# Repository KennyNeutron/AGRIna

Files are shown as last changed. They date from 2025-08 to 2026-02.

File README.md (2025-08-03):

# AGRIna: Smart Soil Analyzer for Rice Crops

## Overview

AGRIna is a portable Arduino & LoRa-based smart soil analyzer designed to help the Department of Agriculture obtain real-time soil condition data directly from the field. By measuring key soil parameters—nitrogen (N), phosphorus (P), and potassium (K) in parts per million (ppm), pH (0–14 scale), and temperature (°C)—AGRIna accelerates decision-making for rice crop management. Data are wirelessly transmitted via LoRa to an ESP32, which forwards readings to a web application featuring live dashboards, historical logs, and simple soil health recommendations.

## Block Diagram

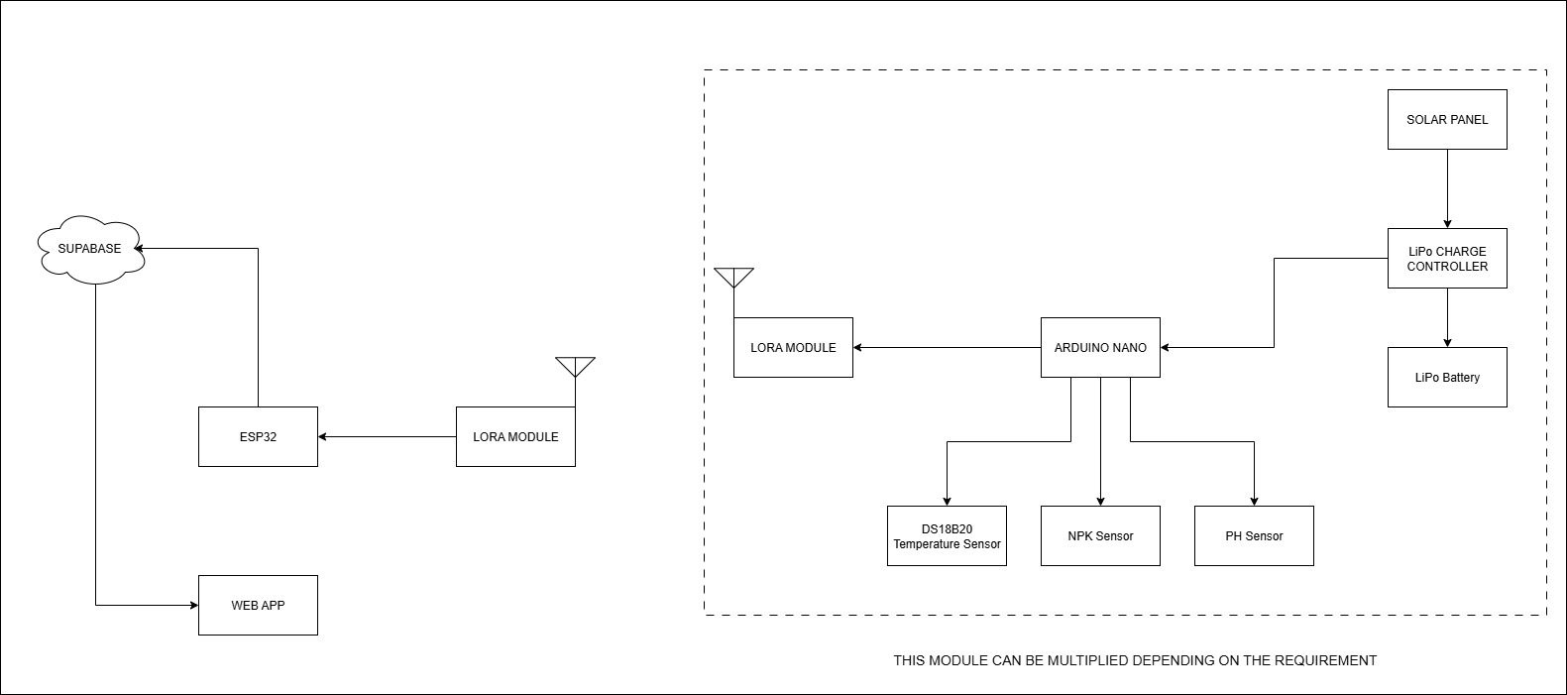
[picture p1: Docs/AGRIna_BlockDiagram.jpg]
Block Diagram


## Features

- **Real-time Sensing**: NPK (ppm), pH (0–14), and temperature (°C)
- **Multi-Module Support**: Up to three simultaneous sensor modules for comparative field analysis
- **Wireless Transmission**: LoRa communication between Arduino nanos and ESP32
- **Web Dashboard**: Live readings, interactive graphs, historical data logs
- **Automated Recommendations**: Simple fertilizer and soil amendment suggestions based on sensor results
- **Power Options**: LiPo battery with charge controller and optional solar panel support

## Hardware Requirements

- **Sensor Module (×3)**
  - Arduino Nano
  - LoRa transceiver
  - DS18B20 temperature sensor
  - NPK soil sensor
  - pH sensor
  - LiPo battery, LiPo charge controller, and solar panel (optional)
- **Central Hub**
  - ESP32 development board
  - LoRa transceiver

## Software Requirements

- Arduino IDE (or PlatformIO) for Nano firmware
- ESP32 toolchain for central hub firmware
- Node.js & npm for web application
- Supabase account (for database and hosting)

## Installation

1. **Clone the repository**

   ```bash
   git clone <repo-url>
   cd AGRIna
   ```

2. **Prepare the Sensor Module**

   - Place `AGRIna_BlockDiagram.jpg` in the project root.
   - Open `sensor_module.ino` in Arduino IDE.
   - Select **Arduino Nano** and upload the sketch.

3. **Flash the ESP32 Hub**

   - Open `hub_firmware.ino` (or PlatformIO project) in your IDE.
   - Select **ESP32** board and upload.

4. **Set Up the Web App**
   ```bash
   cd web-app
   npm install
   npm start
   ```
   - Configure your Supabase URL and anon key in `web-app/.env`.

## Usage

1. Power on each sensor module (via LiPo battery or solar).
2. Modules collect soil data and transmit via LoRa.
3. ESP32 receives, then pushes data to the Supabase backend.
4. Open the web dashboard in your browser to view live data, graphs, and recommendations.

## Contributing

Contributions are welcome! Please fork the repo, create a feature branch, and submit a pull request. For major changes, open an issue first to discuss your ideas.

## License

This project is licensed under the MIT License. See [LICENSE](LICENSE) for details.

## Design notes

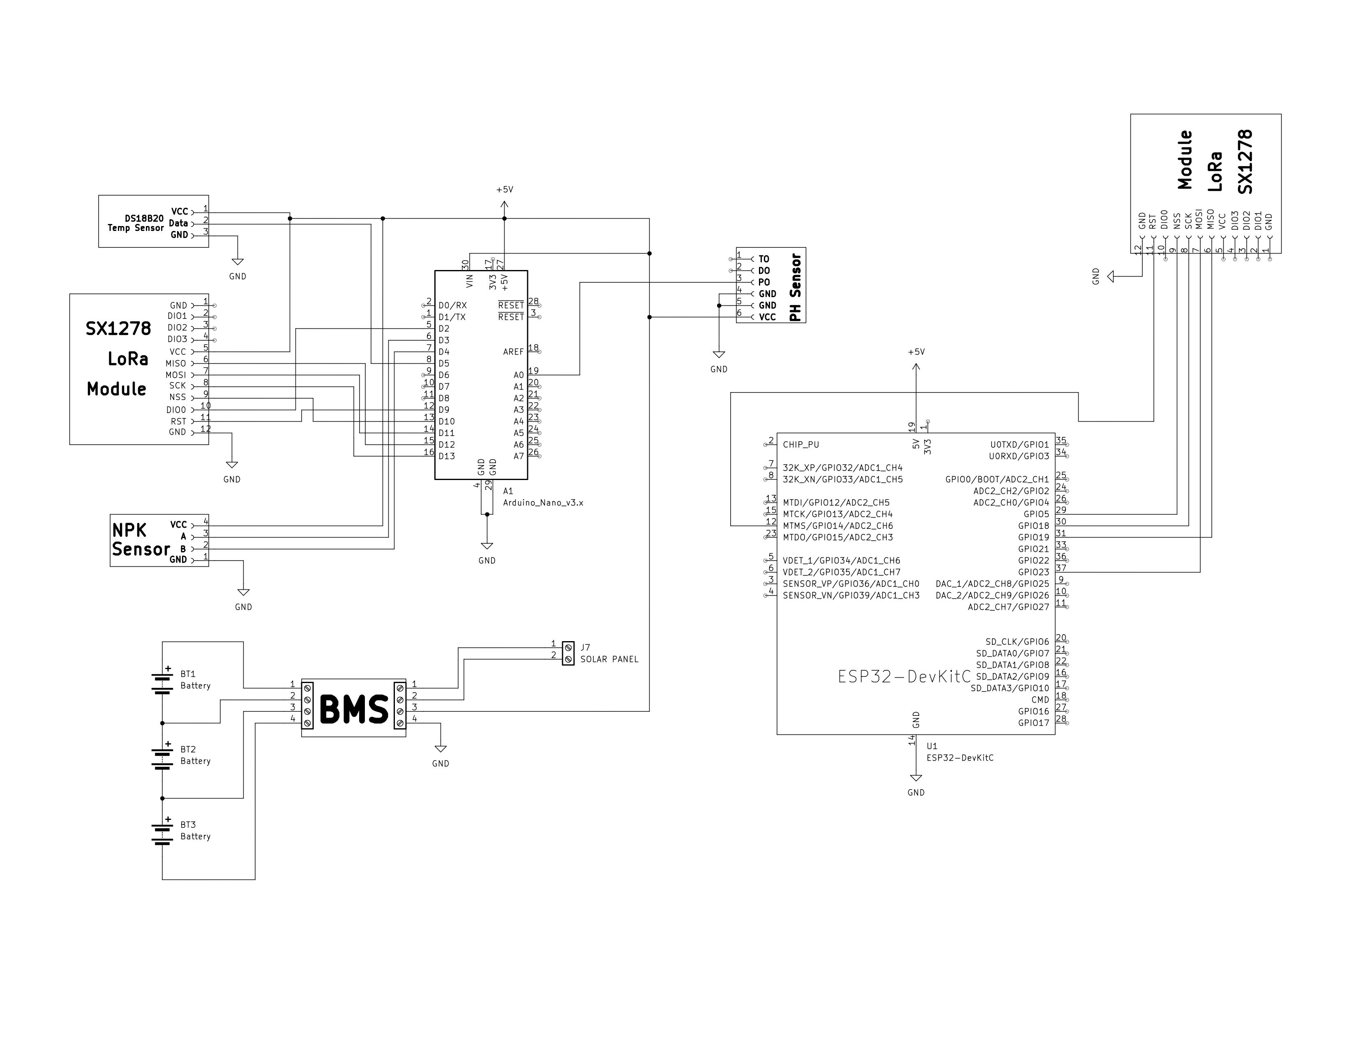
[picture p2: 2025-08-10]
Docs/AGRINa_FullSchematic.jpg

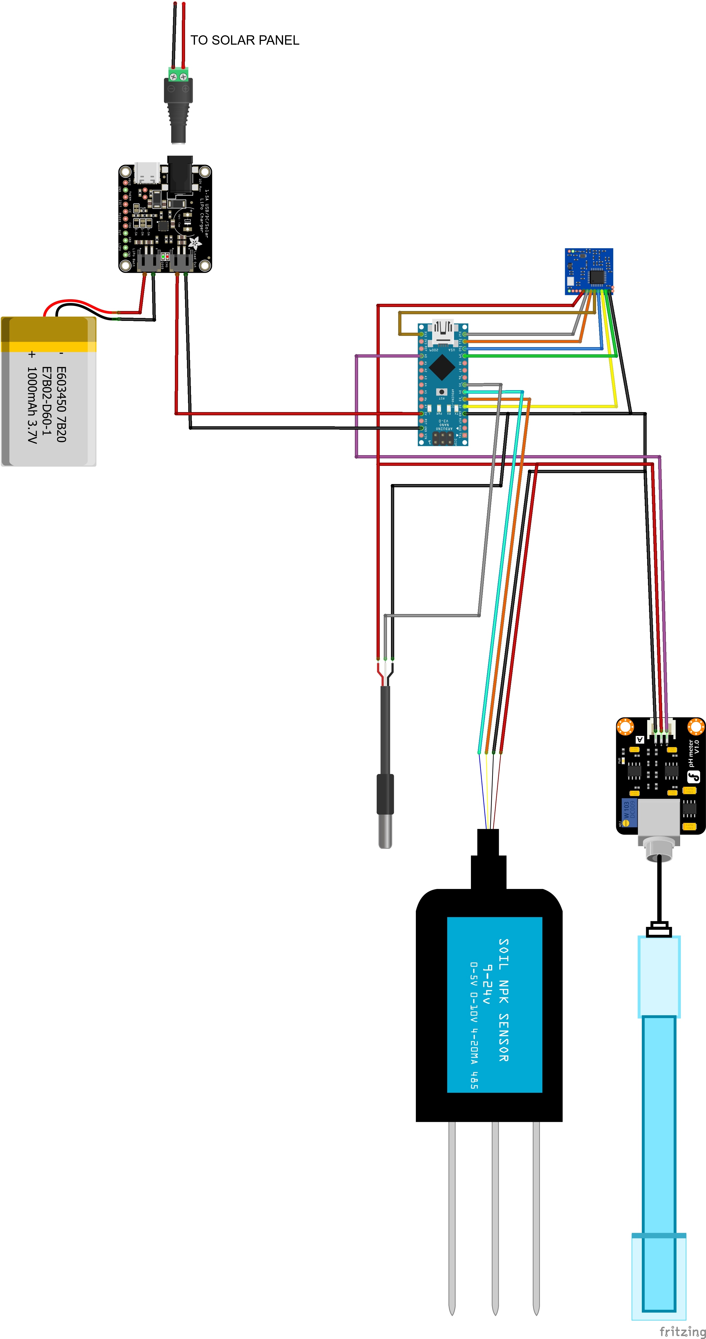
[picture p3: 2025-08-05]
Docs/Agrina Module_bb.jpg

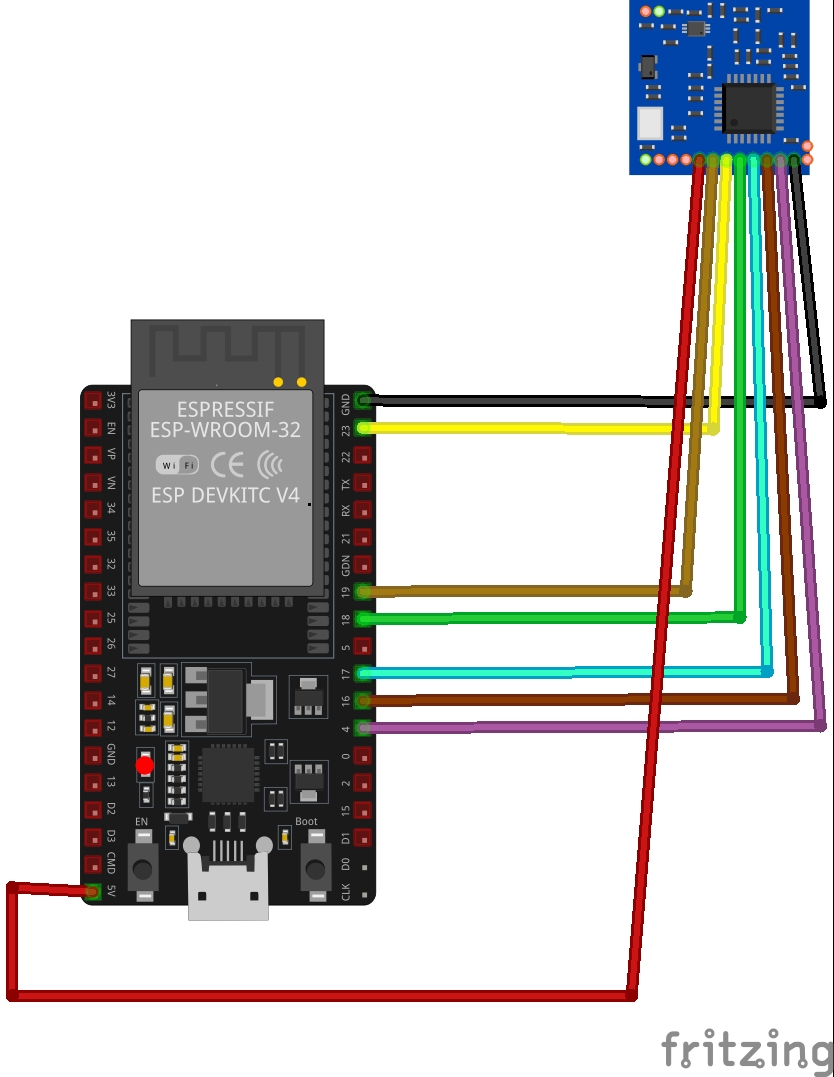
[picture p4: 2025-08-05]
Docs/Agrina Receiver Module_bb.jpg

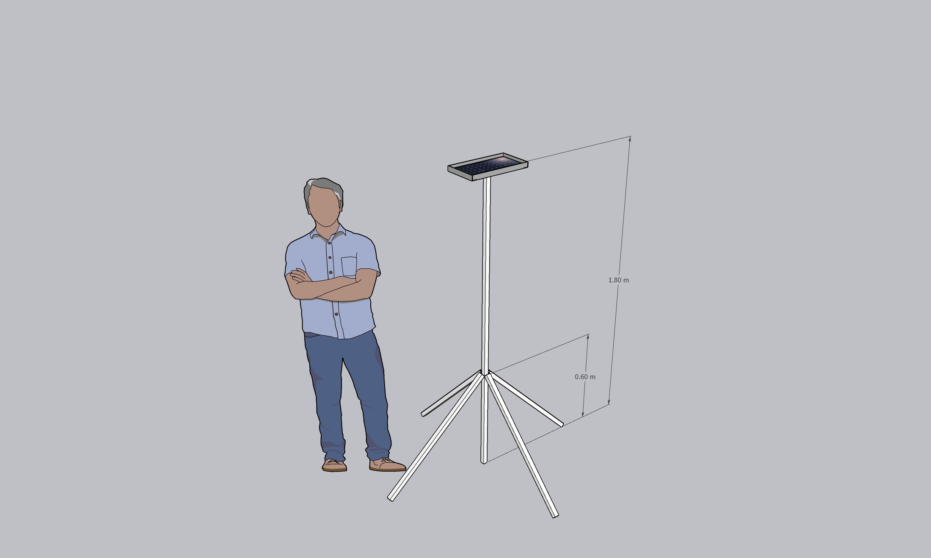
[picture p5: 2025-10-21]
3D/Agrina Struct iso.jpg

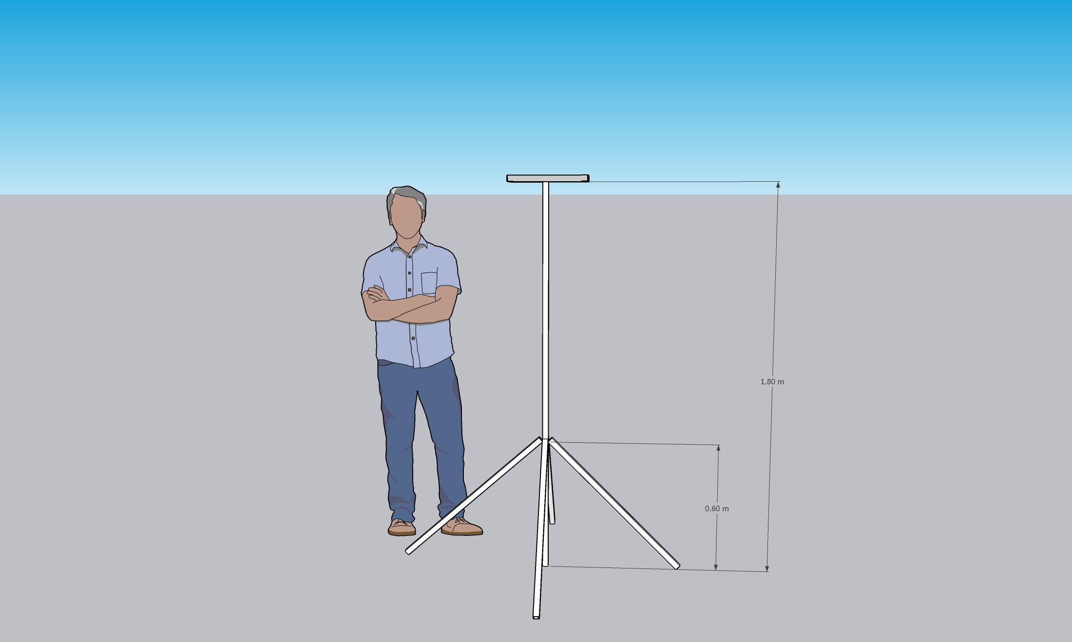
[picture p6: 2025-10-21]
3D/Agrina Struct.jpg

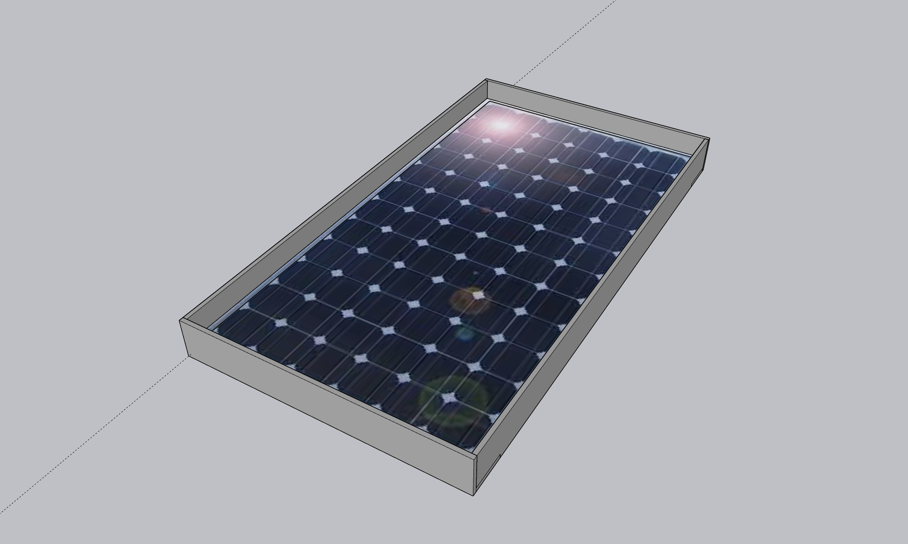
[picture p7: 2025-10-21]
3D/SolarCase_w_Solar.jpg

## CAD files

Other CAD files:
3D/Agrina Struct.skp

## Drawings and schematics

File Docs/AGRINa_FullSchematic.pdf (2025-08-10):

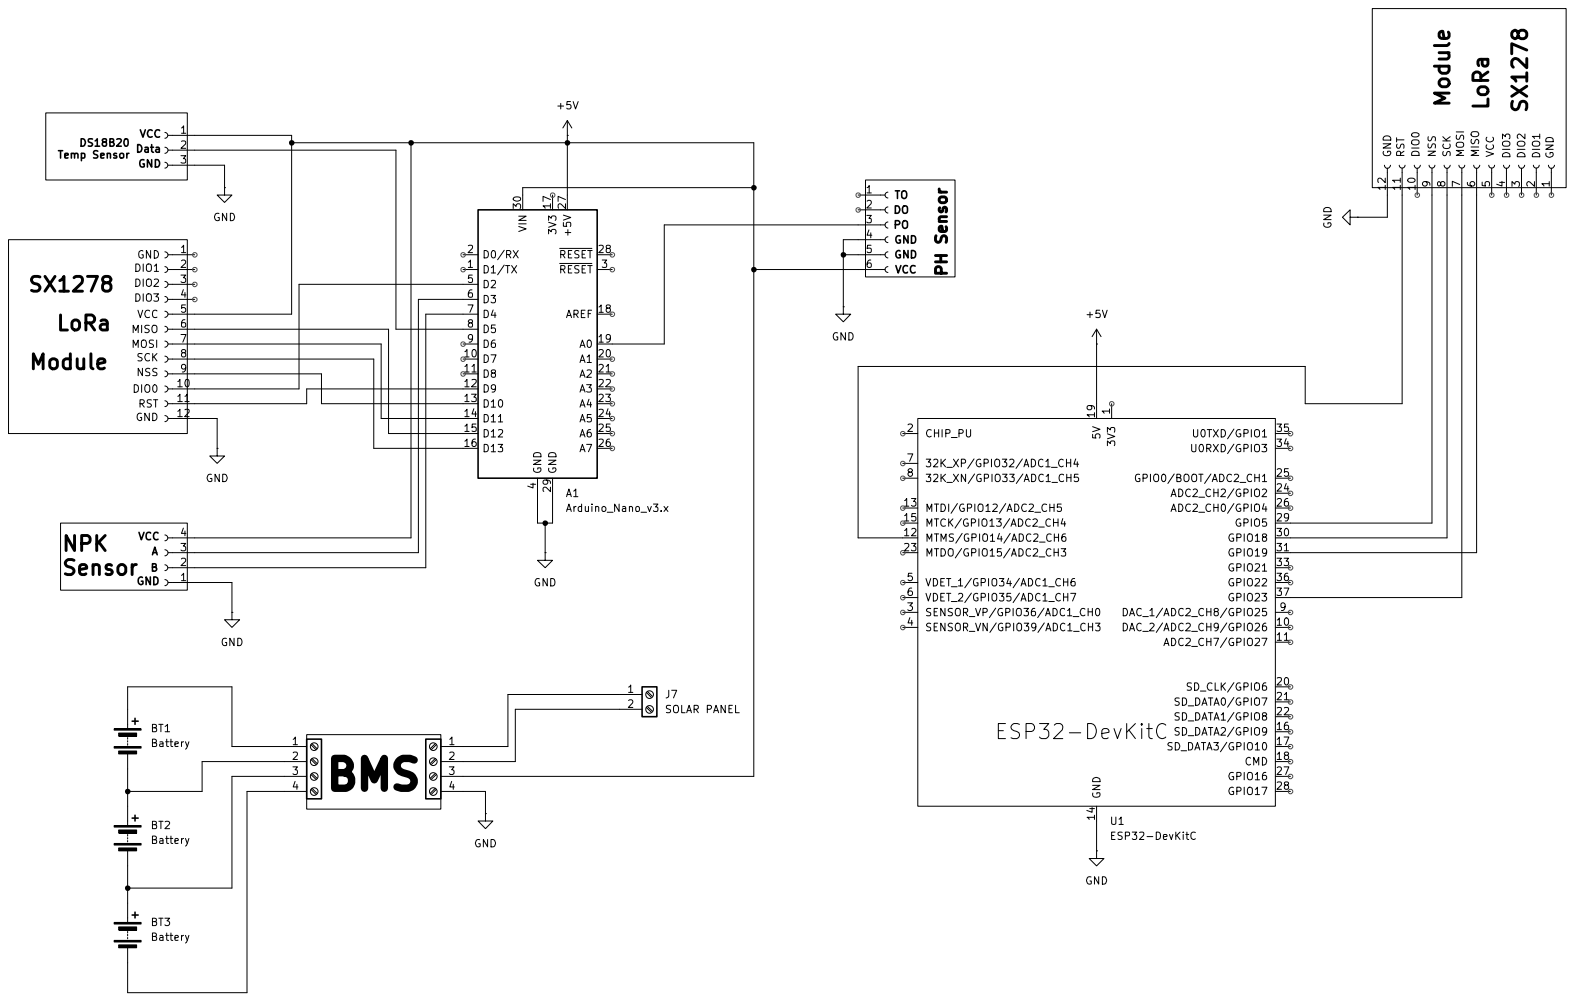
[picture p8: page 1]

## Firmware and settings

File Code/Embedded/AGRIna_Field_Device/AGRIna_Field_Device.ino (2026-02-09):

// AGRIna_Field_Device.ino  —  Transmitter (Arduino Nano + RA-02/SX1278)
// Requires: Sandeep Mistry's LoRa library (Library Manager -> "LoRa" by Sandeep Mistry)

#include <SPI.h>
#include <LoRa.h>
#include "DataStructure.h"  // contains AGRInaData Data_AGRIna (packed)

// === LoRa Radio Pins (Arduino Nano) ===
// NSS(SS)=10, RST=9, DIO0=2  (matches your wiring)
static const int PIN_LORA_SS = 10;
static const int PIN_LORA_RST = 9;
static const int PIN_LORA_DIO0 = 2;

// === LoRa Frequency ===
// Change to 868E6 or 915E6 if you use those bands.
static const long LORA_FREQUENCY = 433E6;

// Device ID
static const uint8_t MY_DEVICE_ID = 0x01;

// Send every N ms
static const uint32_t TX_INTERVAL_MS = 1000UL;
uint32_t lastTx = 0;

// Optional: a simple sequence counter you can add later if needed
uint32_t txCount = 0;

void hexDump(const uint8_t* buf, size_t len) {
  for (size_t i = 0; i < len; i++) {
    if (i && (i % 16 == 0)) Serial.println();
    if (buf[i] < 0x10) Serial.print('0');
    Serial.print(buf[i], HEX);
    Serial.print(' ');
  }
  Serial.println();
}

void setup() {
  Serial.begin(115200);

  Serial.println(F("AGRIna LoRa TX (Arduino Nano + RA-02) starting..."));

  // Set initial values for the struct (for now, static demo values)
  // Tip: Header/Footer can be used for quick packet framing checks
  Data_AGRIna.Header = 0x55;
  Data_AGRIna.AN_DeviceID = MY_DEVICE_ID;
  //   Data_AGRIna.AN_SoilTemperature = 27.5f;
  //   Data_AGRIna.AN_pH = 6.80f;
  //   Data_AGRIna.AN_Nitrogen = 20;  // mg/kg or your chosen unit
  //   Data_AGRIna.AN_Phosphorus = 10;
  //   Data_AGRIna.AN_Potassium = 15;
  Data_AGRIna.Footer = 0xAA;

  // Configure LoRa pins and radio
  LoRa.setPins(PIN_LORA_SS, PIN_LORA_RST, PIN_LORA_DIO0);

  if (!LoRa.begin(LORA_FREQUENCY)) {
    Serial.println(F("[ERR] LoRa init failed. Check wiring/frequency."));
    while (true) { delay(1000); }
  }

  // Optional radio tweaks
  LoRa.setTxPower(17);             // 2..20 (dBm), watch legal limits
  LoRa.setSpreadingFactor(7);      // 6..12
  LoRa.setSignalBandwidth(125E3);  // 7.8E3..500E3
  LoRa.setCodingRate4(5);          // 5..8

  Serial.print(F("Struct size (bytes): "));
  Serial.println(sizeof(Data_AGRIna));
  Serial.println(F("Initial payload (hex):"));
  hexDump(reinterpret_cast<uint8_t*>(&Data_AGRIna), sizeof(Data_AGRIna));

  lastTx = millis();

  SoilSensor_setup();
}

void loop() {
  SoilSensor_loop();

  // Check for incoming packets (Repeater Logic)
  int packetSize = LoRa.parsePacket();
  if (packetSize == sizeof(AGRInaData)) {
    AGRInaData receivedData;
    LoRa.readBytes((uint8_t*)&receivedData, sizeof(receivedData));

    // Validate Header, Footer and ensure it's not from us
    if (receivedData.Header == 0x55 && receivedData.Footer == 0xAA && receivedData.AN_DeviceID != MY_DEVICE_ID) {
      Serial.print(F("Repeater: RX from 0x"));
      Serial.println(receivedData.AN_DeviceID, HEX);

      delay(random(50, 200));  // Random delay to minimize collisions

      LoRa.beginPacket();
      LoRa.write((uint8_t*)&receivedData, sizeof(receivedData));
      LoRa.endPacket();

      Serial.println(F("Repeater: Fwd done."));
    }
  }

  const uint32_t now = millis();
  if (now - lastTx >= TX_INTERVAL_MS) {
    lastTx = now;

    // (Optional) Mutate values here if you want to see changes over time
    // Example: Data_AGRIna.AN_SoilTemperature += 0.1f;

    // Transmit the raw struct
    LoRa.beginPacket();
    LoRa.write((uint8_t*)&Data_AGRIna, sizeof(Data_AGRIna));
    LoRa.endPacket();

    txCount++;
    Serial.print(F("TX #"));
    Serial.print(txCount);
    Serial.print(F("  bytes="));
    Serial.print(sizeof(Data_AGRIna));
    Serial.print(F("  ID="));
    Serial.print(Data_AGRIna.AN_DeviceID);
    Serial.print(F("  T="));
    Serial.print(Data_AGRIna.AN_SoilTemperature, 2);
    Serial.print(F("  pH="));
    Serial.print(Data_AGRIna.AN_pH, 2);
    Serial.print(F("  NPK="));
    Serial.print(Data_AGRIna.AN_Nitrogen);
    Serial.print('/');
    Serial.print(Data_AGRIna.AN_Phosphorus);
    Serial.print('/');
    Serial.print(Data_AGRIna.AN_Potassium);
    Serial.println();
  }
}

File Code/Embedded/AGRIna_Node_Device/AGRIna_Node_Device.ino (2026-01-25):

#include "variables.h"
#include <WiFi.h>
#include <HTTPClient.h>
#include <SPI.h>
#include <LoRa.h>
#include "DataStructure.h"  // defines packed AGRInaData + global Data_AGRIna (unused here) :contentReference[oaicite:1]{index=1}

// ==== ESP32 LoRa Pins (match your wiring) ====
static const int PIN_LORA_SS = 5;     // NSS / CS
static const int PIN_LORA_RST = 14;   // RESET
static const int PIN_LORA_DIO0 = 26;  // DIO0

// ==== LoRa Radio Settings ====
static const long LORA_FREQUENCY = 433E6;  // change to 868E6 or 915E6 as applicable

// Optional: Expected header/footer for quick validation
static const uint8_t kHeader = 0x55;
static const uint8_t kFooter = 0xAA;

uint32_t last_update = 0;
uint32_t Supabase_Update_Interval = 10000;

uint8_t rxDeviceID = 0;

void hexDump(const uint8_t* buf, size_t len) {
  for (size_t i = 0; i < len; i++) {
    if (i && (i % 16 == 0)) Serial.println();
    if (buf[i] < 0x10) Serial.print('0');
    Serial.print(buf[i], HEX);
    Serial.print(' ');
  }
  Serial.println();
}

void setup() {
  Serial.begin(115200);
  Serial.println("AGRIna Node Device Starting...");
  LED_Setup();

  WiFi.begin(ssid, password);
  Serial.println("Connecting to WiFi");
  while (WiFi.status() != WL_CONNECTED) {
    LEDred_On();
    delay(200);
    LEDred_Off();
    delay(200);
    Serial.print(".");
  }
  LEDred_Off();
  LEDgreen_On();
  Serial.println("Connected to WiFi");

  Serial.println(F("\nAGRIna LoRa RX (ESP32 + RA-02) starting..."));
  Serial.print(F("Expecting payload bytes: "));
  Serial.println(sizeof(AGRInaData));

  LoRa.setPins(PIN_LORA_SS, PIN_LORA_RST, PIN_LORA_DIO0);
  if (!LoRa.begin(LORA_FREQUENCY)) {
    Serial.println(F("[ERR] LoRa init failed. Check wiring/frequency."));
    for (;;) { delay(1000); }
  }

  // Optional radio tuning (match TX if you changed these there)
  LoRa.setSpreadingFactor(7);
  LoRa.setSignalBandwidth(125E3);
  LoRa.setCodingRate4(5);

  Serial.println(F("[OK] LoRa ready. Waiting for packets..."));
  last_update = millis();
}

void loop() {

  int packetSize = LoRa.parsePacket();
  if (packetSize <= 0) return;

  Serial.println(F("\n--- Packet Received ---"));
  Serial.print(F("packetSize="));
  Serial.print(packetSize);
  Serial.print(F("  RSSI="));
  Serial.print(LoRa.packetRssi());
  Serial.print(F("  SNR="));
  Serial.println(LoRa.packetSnr(), 1);

  // Read all available bytes
  uint8_t buf[64];  // plenty for this struct
  int idx = 0;
  while (LoRa.available() && idx < (int)sizeof(buf)) {
    buf[idx++] = LoRa.read();
  }

  if (idx != (int)sizeof(AGRInaData)) {
    Serial.print(F("[WARN] Unexpected size. Got "));
    Serial.print(idx);
    Serial.print(F(", expected "));
    Serial.println(sizeof(AGRInaData));
    Serial.println(F("Hex dump:"));
    hexDump(buf, idx);
    return;
  }

  // Reconstruct struct
  AGRInaData rx{};
  memcpy(&rx, buf, sizeof(rx));

  // Validate header/footer
  bool ok = (rx.Header == kHeader) && (rx.Footer == kFooter);

  if (!ok) {
    Serial.println(F("[WARN] Header/Footer invalid. Dumping bytes:"));
    Serial.print(F("Header=0x"));
    Serial.print(rx.Header, HEX);
    Serial.print(F("  Footer=0x"));
    Serial.println(rx.Footer, HEX);
    hexDump(buf, idx);
    return;
  }

  // Print decoded fields
  Serial.println(F("[OK] Valid AGRInaData payload"));
  Serial.print(F("DeviceID: "));
  Serial.println(rx.AN_DeviceID);
  Serial.print(F("Soil Temp (°C): "));
  Serial.println(rx.AN_SoilTemperature, 2);
  Serial.print(F("pH: "));
  Serial.println(rx.AN_pH, 2);
  Serial.print(F("Nitrogen: "));
  Serial.println(rx.AN_Nitrogen);
  Serial.print(F("Phosphorus: "));
  Serial.println(rx.AN_Phosphorus);
  Serial.print(F("Potassium: "));
  Serial.println(rx.AN_Potassium);

  rxDeviceID=rx.AN_DeviceID;

  if ((millis() - last_update) > Supabase_Update_Interval) {
    Serial.println("\n\n\nSupa Update!!!\n\n\n");
    SupabaseUpdate(rx.AN_pH, rx.AN_SoilTemperature, rx.AN_Nitrogen, rx.AN_Phosphorus, rx.AN_Potassium);
    last_update = millis();
  }
}

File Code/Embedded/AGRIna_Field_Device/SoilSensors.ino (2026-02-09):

// File: Dual_RS485_Soil_NPK_SEN0605_or_AutoScan.ino
// Board: Arduino Nano/Uno (ATmega328P)
//
// Links (each probe has its own MAX485):
//   NPK probe  (Probe A): RO=D3, RE&DE=D4, DI=D5
//   5-in-1 probe (Probe B): RO=D6, RE&DE=D7, DI=D8
//
// Both probes run at 4800-8-N-1 here and both are ID=0x01
// (that’s OK because they are on different transceivers).
//
// Behavior:
// 1) Try DFRobot SEN0605 map for NPK (FC03 @ 0x001E..0x0020).
// 2) If that fails or returns all zeros, auto-scan common maps (FC03/FC04).
// 3) Print which method was adopted.
//
// Optional: send 'd' over Serial to dump some NPK raw registers (debug).

#include <SoftwareSerial.h>

// ---------------- Pins --------------------
// Probe A: NPK
#define A_RO_PIN 3
#define A_DI_PIN 5
#define A_REDE_PIN 4
SoftwareSerial RS485_A(A_RO_PIN, A_DI_PIN);  // (RX, TX)

// Probe B: 5-in-1 (Moisture, Temp, EC, pH)
#define B_RO_PIN 6
#define B_DI_PIN 8
#define B_REDE_PIN 7
SoftwareSerial RS485_B(B_RO_PIN, B_DI_PIN);  // (RX, TX)

// ---------------- Serial/Modbus settings ---------------
const uint32_t MB_BAUD = 4800;   // your devices work at 4800
const uint16_t TIMEOUTMS = 800;  // a bit generous at 4800

// Both are 0x01 (separate ports)
const uint8_t NPK_ID = 0x01;
const uint8_t SOIL5_ID = 0x01;

// 5-in-1 register map (common defaults)
const uint16_t SOIL5_START = 0x0000;  // Moist, Temp, EC, pH
const uint16_t SOIL5_COUNT = 4;

// DFRobot SEN0605 fixed map (per docs)
const uint8_t SEN_FC = 0x03;
const uint16_t SEN_BASE = 0x001E;  // N,P,K at 0x001E..0x0020

// ---------------- Helpers -----------------
uint16_t modbusCRC(const uint8_t *buf, uint8_t len) {
  uint16_t crc = 0xFFFF;
  for (uint8_t pos = 0; pos < len; pos++) {
    crc ^= buf[pos];
    for (uint8_t i = 0; i < 8; i++) {
      if (crc & 1) {
        crc >>= 1;
        crc ^= 0xA001;
      } else {
        crc >>= 1;
      }
    }
  }
  return crc;
}

inline void disableBothDrivers() {
  digitalWrite(A_REDE_PIN, LOW);
  digitalWrite(B_REDE_PIN, LOW);
}

// Generic Modbus read (FC = 0x03 or 0x04)
bool mbReadRegsFC(SoftwareSerial &port, uint8_t txEnPin,
                  uint8_t id, uint8_t fc, uint16_t startReg, uint16_t count,
                  uint16_t *outRegs, uint16_t timeoutMs = TIMEOUTMS) {

  uint8_t req[8] = {
    id, fc,
    (uint8_t)(startReg >> 8), (uint8_t)(startReg & 0xFF),
    (uint8_t)(count >> 8), (uint8_t)(count & 0xFF),
    0, 0
  };
  uint16_t crc = modbusCRC(req, 6);
  req[6] = (uint8_t)(crc & 0xFF);
  req[7] = (uint8_t)(crc >> 8);

  port.listen();                         // switch SoftwareSerial listener
  while (port.available()) port.read();  // clear stale bytes

  disableBothDrivers();         // only one transceiver active
  digitalWrite(txEnPin, HIGH);  // TX enable for this transceiver
  port.write(req, sizeof(req));
  port.flush();
  delay(6);                    // 4800 baud turnaround
  digitalWrite(txEnPin, LOW);  // RX

  // Expect: [ID][FC][ByteCount=2*count][data...][CRCLo][CRCHi]
  uint8_t buf[48];
  uint8_t idx = 0;
  unsigned long t0 = millis();
  while (millis() - t0 < timeoutMs) {
    if (port.available()) {
      if (idx < sizeof(buf)) buf[idx++] = port.read();
      if (idx >= 3) {
        uint8_t bc = buf[2];
        if (idx >= 3 + bc + 2) break;  // full frame received
      }
    }
  }
  if (idx < 7) return false;
  if (buf[0] != id || buf[1] != fc) return false;
  if (buf[2] != count * 2) return false;

  uint16_t rxCrc = (uint16_t)buf[idx - 1] << 8 | buf[idx - 2];
  uint16_t calc = modbusCRC(buf, idx - 2);
  if (rxCrc != calc) return false;

  for (uint16_t i = 0; i < count; i++)
    outRegs[i] = (uint16_t)buf[3 + 2 * i] << 8 | buf[4 + 2 * i];

  return true;
}

// Optional writer: FC=0x06 (set single holding register)
//  - 0x07D0: device address
//  - 0x07D1: baud (0=2400, 1=4800, 2=9600)
bool mbWriteReg06(SoftwareSerial &port, uint8_t txEnPin,
                  uint8_t id, uint16_t reg, uint16_t value,
                  uint16_t timeoutMs = TIMEOUTMS) {
  uint8_t req[8] = {
    id, 0x06,
    (uint8_t)(reg >> 8), (uint8_t)(reg & 0xFF),
    (uint8_t)(value >> 8), (uint8_t)(value & 0xFF),
    0, 0
  };
  uint16_t crc = modbusCRC(req, 6);
  req[6] = (uint8_t)(crc & 0xFF);
  req[7] = (uint8_t)(crc >> 8);

  port.listen();
  while (port.available()) port.read();

  disableBothDrivers();
  digitalWrite(txEnPin, HIGH);
  port.write(req, sizeof(req));
  port.flush();
  delay(6);
  digitalWrite(txEnPin, LOW);

  // Expect echo of the same 8 bytes
  uint8_t resp[8];
  uint8_t idx = 0;
  unsigned long t0 = millis();
  while (millis() - t0 < timeoutMs && idx < 8) {
    if (port.available()) resp[idx++] = port.read();
  }
  if (idx != 8) return false;
  return memcmp(resp, req, 8) == 0;
}

// ---------------- 5-in-1 reader ----------------
bool readSoil5(float &moist_pct, float &temp_c, float &ec_uScm, float &ph) {
  uint16_t r[SOIL5_COUNT];
  if (!mbReadRegsFC(RS485_B, B_REDE_PIN, SOIL5_ID, 0x03, SOIL5_START, SOIL5_COUNT, r))
    return false;

  // Common scaling (adjust if your leaflet differs)
  moist_pct = r[0] / 10.0f;  // 0.1% → %
  temp_c = r[1] / 10.0f;     // 0.1°C → °C
  ec_uScm = r[2];            // µS/cm
  ph = r[3] / 100.0f;        // 0.01 → pH
  return true;
}

// ---------------- NPK: fixed SEN0605 + autoscan fallback ----------------
struct NpkLock {
  bool ok = false;
  uint8_t fc = 0x03;
  uint16_t base = 0x001E;
  bool byScan = false;
} npk;

static inline bool allZero(uint16_t a, uint16_t b, uint16_t c) {
  return (a == 0 && b == 0 && c == 0);
}
static inline bool plausible(uint16_t n, uint16_t p, uint16_t k) {
  // very loose; prevents locking on garbage
  return (n < 30000 && p < 30000 && k < 30000) && !allZero(n, p, k);
}

// First try the official SEN0605 mapping
bool readNPK_SEN0605(uint16_t &N, uint16_t &P, uint16_t &K) {
  uint16_t r[3];
  if (!mbReadRegsFC(RS485_A, A_REDE_PIN, NPK_ID, SEN_FC, SEN_BASE, 3, r)) return false;
  N = r[0];
  P = r[1];
  K = r[2];
  return true;
}

// Scan common spots if the fixed map is zero/not responding
bool scanAndLockNPK(uint16_t &N, uint16_t &P, uint16_t &K) {
  const struct {
    uint8_t fc;
    uint16_t base;
  } tries[] = {
    { 0x03, 0x0001 },
    { 0x04, 0x0001 },
    { 0x03, 0x001E },
    { 0x04, 0x001E },
    { 0x03, 0x0004 },
    { 0x04, 0x0004 },
    { 0x03, 0x0031 },
    { 0x04, 0x0031 },
  };

  uint16_t r[3];
  for (uint8_t i = 0; i < sizeof(tries) / sizeof(tries[0]); i++) {
    if (mbReadRegsFC(RS485_A, A_REDE_PIN, NPK_ID, tries[i].fc, tries[i].base, 3, r)) {
      if (plausible(r[0], r[1], r[2])) {
        npk.ok = true;
        npk.fc = tries[i].fc;
        npk.base = tries[i].base;
        npk.byScan = true;
        N = r[0];
        P = r[1];
        K = r[2];
        Serial.print(F("[NPK] Locked by scan: FC0x"));
        Serial.print(npk.fc, HEX);
        Serial.print(F(" @ 0x"));
        Serial.println(npk.base, HEX);
        return true;
      }
    }
  }
  return false;
}
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

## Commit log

2025-08-05 added files for the schematic/wiring diagram of the system (by parts)
    [Agrina Module.fzz, Agrina Receiver Module.fzz]
2025-08-10 added KiCAD files for the full schematic diagram of the project (as one)
    [AGRINa.kicad_pcb, AGRINa.kicad_sch]
2025-09-12 added initial embedded systems files
    [AGRINa.kicad_sch]
2025-10-21 restarted nextjs proj. login page now works (no BE yet)
    [Agrina Struct.skp]
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2025-12-13 feat: Add initial dashboard home page with device monitoring UI and statistics.
2025-12-13 feat: add live sensor readings dashboard page with real-time soil condition monitoring.
2025-12-13 feat: implement user authentication actions and initial dashboard UI for device monitoring.
2025-12-14 feat: implement settings page with user profile, device, notification, and data management options, along with new dependencies and a switch UI component.
2025-12-14 docs: Add initial database schema documentation for AGRina, detailing seven tables including profiles, devices, sensor readings, and deployments.
2025-12-14 feat: introduce dashboard page with device overview, layout, sidebar, and RLS policies
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2025-12-14 feat: implement live sensor readings dashboard page with device selection and detailed sensor metrics.
2025-12-14 feat: Implement ESP32 code to connect to WiFi and send dummy sensor data to Supabase via HTTP POST.
2025-12-16 feat: Implement web settings for profile, device, and user preferences, alongside initial LoRa communication for field and node devices.
2026-01-19 refactor: Clean up formatting and improve code readability in LoRa and Soil Sensor files
2026-01-24 fix: Update AN_DeviceID to 0x03 for correct device identification
    [AGRIna_Field_Device.ino]
2026-01-25 feat: Implement initial LoRa transmitter code for AGRIna field device on Arduino Nano.
2026-01-25 feat: Implement LoRa sensor data reception and Supabase upload for the embedded node, and add the web application login page.
2026-01-25 feat: Implement initial dashboard overview and live readings pages for device monitoring.
2026-01-25 feat: implement dashboard home page displaying system statistics and selected device details, along with new device selection and live dashboard components.
2026-01-25 feat: Introduce device deployment functionality and a history dashboard with data visualization.
2026-01-25 feat: implement dashboard history page with sensor data trends, logs, and deployment records.
2026-01-28 Adds device deployment details and date picker
    Implements the ability to record device deployment details, including lot owner, deployment dates, coordinates, crop type, and field description.
    Integrates `@radix-ui/react-popover`, `react-day-picker`, and `date-fns` for date selection in the deployment dialog.
    Includes new device fields in the database schema and form submission logic.
2026-01-28 Enhances history page with device details
    Improves the history page by displaying additional device details such as lot owner, crop type, firmware version, last seen, and field specifications.
    Removes the deployment filter as it's functionality is currently not needed.
    Reduces the number of columns in the filter section to better utilize screen space.
2026-01-28 Improves device status display in history page
    Updates the device cards on the history page to display device connection status (online/offline) and last seen time.
    This enhances the user experience by providing real-time status information for each device.
2026-01-28 Improves device history page with filtering
    Adds device selection and search functionality to the history page.
    This allows users to filter data based on a specific device or search for devices and readings by name, serial number, owner, crop type, or recorded date.
    The changes include:
    - Adding a device selection dropdown to filter the displayed data
    - Implementing a search bar to filter the device list and readings
    - Updating the data fetching logic to include device filtering
    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
2026-02-09 feat: Implement initial LoRa transmission and Modbus RTU soil sensor reading for the AGRIna field device.
2026-02-09 Implements deployment history card view
    Introduces a detailed card view for displaying device deployment history.
    This card includes device information, deployment period, sensor data statistics,
    and the latest readings, providing a comprehensive overview of each deployment.
    It replaces the previous basic card with a more informative and user-friendly
    representation of deployment data. Also, auto-switches to "all" time range
    when viewing deployment records to ensure stats are accurate.
2026-02-17 Implements deployment details dialog
    Adds a dialog to display detailed information about a deployment, including sensor readings and device metadata.
    The dialog includes a table of sensor readings with timestamp, pH, temperature, nitrogen, phosphorus, and potassium values. It also provides details about the deployment location, duration, and crop 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
    A CSV export button is included to download the data.
2026-03-10 Standardizes nutrient units to ppm
    Updates the measurement unit for nitrogen, phosphorus, and potassium from milligrams per kilogram (mg/kg) to parts per million (ppm) across the database schema, UI displays, and export functionalitie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
    Ensures consistent representation of nutrient levels throughout the application.
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
